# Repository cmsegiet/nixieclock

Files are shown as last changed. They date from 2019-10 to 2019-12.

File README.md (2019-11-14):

# Nixie Tube Clock
Classic Nixie Tube Clock with Bluetooth/WiFi capability

### Background

The nixie tube displays are fascinating to look at and were used in many Cold War era test equipment and various other devices. I was inspired by many nixie tube clock designs to design my own as well. On the surface, this project seemed very easy. However, the deeper I got into the design phase, I quickly realized I had to learn more about designing switching power supplies to get a high voltage rail for the nixie tubes from a much smaller wall adapter. As well as wanting to learn more about transmission lines and impedance matching for implementing a Printed Inverted F Antenna (PIFA) or in general terms, a microstrip antenna with a resonant frequency of 2.4GHz for WiFi capability. 

### Design Requirements

- WiFi-enabled for configuration and additional features such as a remotely accessible timer or scoreboard. 
- RTC module or integrated RTC to allow time-keeping during failures
- A low voltage power supply such as 5V to 12V wall adapter
- Rotary encoder w/ momentary push button for user control
- Direct drive for Nixie Tubes
- 160V to 180V power supply @ 10mA to drive 4 IN-12A Nixie Tubes (Each tube sinks about 2.5mA at 180VDC)

### Design Implementation Features

- Chose nRF52832 MCU from Nordic Semiconductor w/ integrated RTC and Quadrature Decoder for encoder
- Serial to Parallel Shift Register w/ open-drain latched outputs (also 50V Zener clamped common, discussed later) for tubes
- LM3478 Boost/flyback controller for generating 180VDC
- 3.3V boost regulator for MCU
- 5V boost regulator for shift registers and other IC's
- Barrel jack input for wall adapter allowing about 5V to 12V input (protected by TVS diode and Schottky diode, as well as fused)
- I2C Temperature sensor for monitoring overall system temperature
- Later decided to implement this as a multi-board project with a front panel PCB for Nixie's and a control board for MCU for modularity

## Progress

Just a picture of one of the nixie tubes while testing out the power supply section.

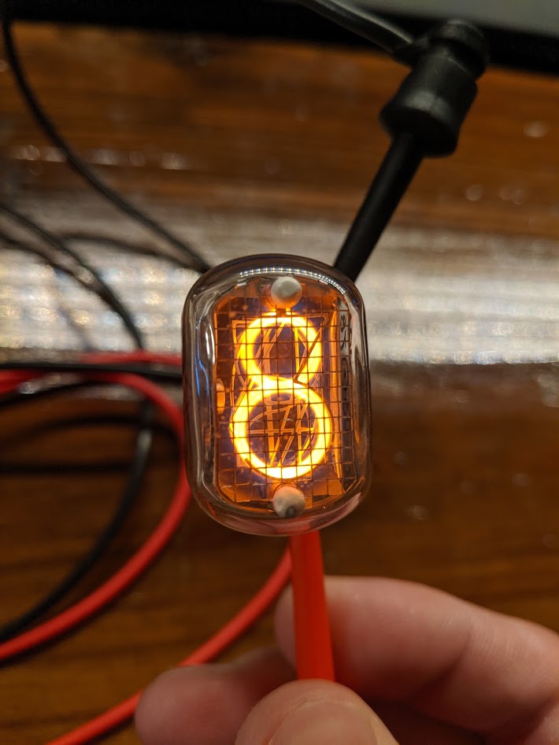
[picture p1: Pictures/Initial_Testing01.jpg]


### 2019-08-18

Purchased a power supply module designed by Paul Andrews on Hackaday to learn more about designing and understanding switching power supply design. Ultimately, I decided to implement most of Paul's design with minor changes such as a different switching FET due to availability of parts. I'll have to monitor the temperature of the new FET although the FET I chose has similar paramters such as Rds(on), Coss, Vds max, gate drive voltage, etc. 

Also spent alot of time in this month learning more about Nixie Tubes and how they work and how they are driven. I learned that they could be driven by a "lower" voltage shift register if the digits that aren't being used at the time are clamped to a common 50V zener on the driver. With this configuration, a dedicated HV driver chip or discrete HV transistors aren't needed. Since the maintainence voltage to keep a Nixie lit after ignition is around 120V, we'll have to lower the supply voltage to around 160V. This will prevent other numbers that aren't being selected from lighting up partially since when they are clamped by a 50V zener, they'll be sitting at around 110V, which is not enough to maintain ignition in a Nixie. By the way 160V is enough to ignite the Nixie's as well, although a common figure tossed around is 170V to 180V.

### 2019-10-12

Finshed most of the schematics, just refining and adding additional features

### 2019-11-05

Finished PCB layout of the control board and figured out how to create a Multi-Board project within Altium Designer. 

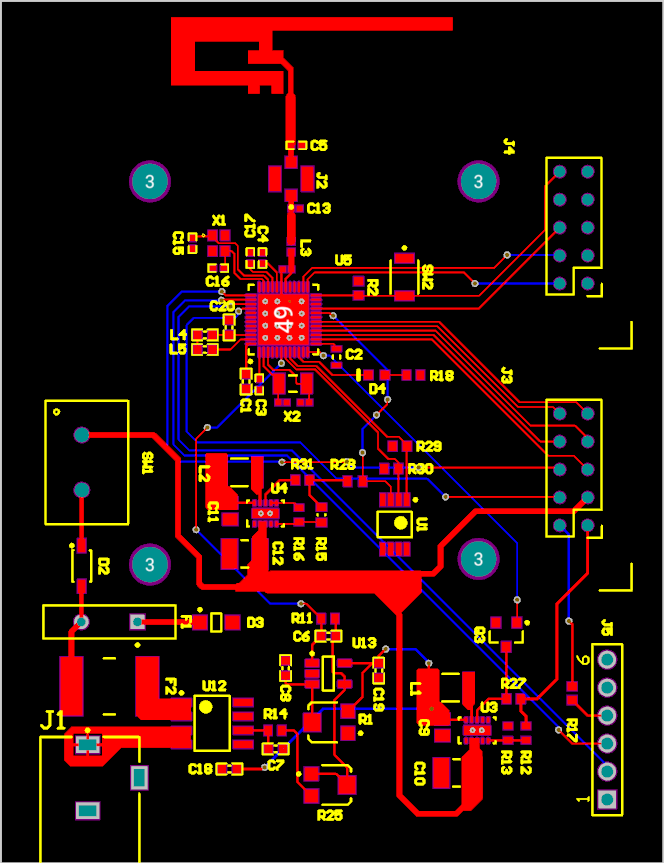
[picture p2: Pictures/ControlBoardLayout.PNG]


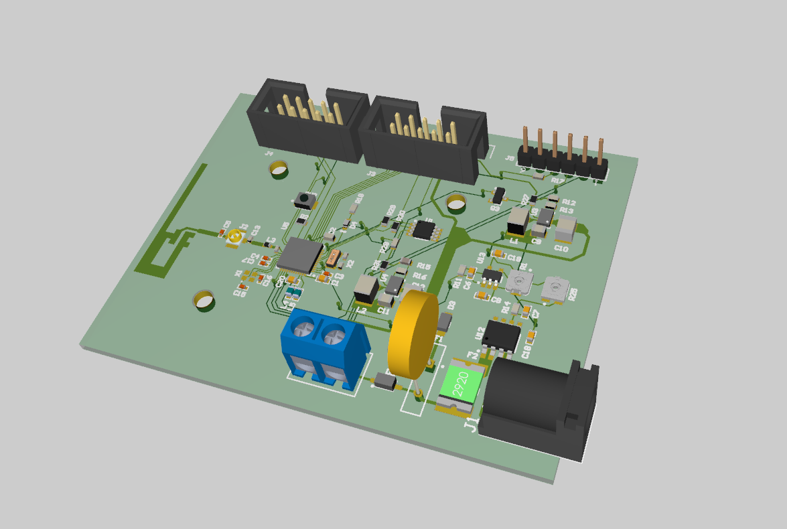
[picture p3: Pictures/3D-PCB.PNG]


### Up Next!

No ground or power planes added yet, but looking good so far! Next up is adding planes and connecting 3v3 through via's to the power plane, as well as adding a via fence for the microstrip antenna ground connections.

I was also thinking about how I could test the antenna S-parameters upon assembly, but this may not be possible due to lack of access to a network analyzer. Unfortunately, the cheap mini VNA's on Amazon and such do not go up to 2.4GHz. Regardless of this shortcoming, I did include a pi-network filter just in case this testing becomes possible.

After finishing the control board, I'll start working on the Nixie Tube board or front panel of the clock. The tricky part with this portion will be finding an adequate source for IN-12A Nixie tube sockets, since the pin dimensions are not consistent enough for a direct IN-12A footprint.

### 2019-11-10

Completed layout of the control board with via shielding along microstrip transmission line, and via stitching GND planes together:

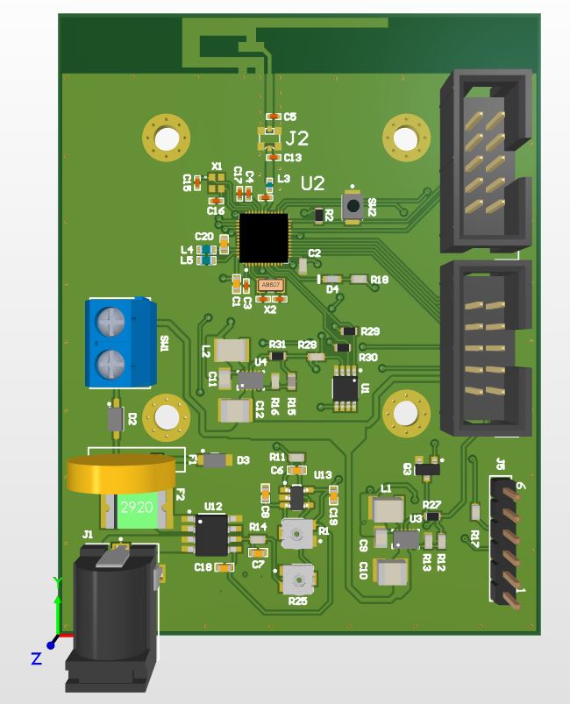
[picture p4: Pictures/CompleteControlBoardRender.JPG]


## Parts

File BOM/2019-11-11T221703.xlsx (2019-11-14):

Index | Quantity | Part Number | Manufacturer Part Number | Description | Customer Reference | Available | Backorder | Unit Price | Extended Price USD
1 | 20 | 587-1441-1-ND | LMK107BJ475KA-T | CAP CER 4.7UF 10V X5R 0603 |  | 20 | 0 | 0.116 | 2.32
2 | 100 | 399-1099-1-ND | C0603C104M4RACTU | CAP CER 0.1UF 16V X7R 0603 |  | 100 | 0 | 0.0161 | 1.61
3 | 100 | 399-1043-1-ND | C0402C104Z4VAC7867 | CAP CER 0.1UF 16V Y5V 0402 |  | 100 | 0 | 0.0081 | 0.81
4 | 100 | 311-1024-1-ND | CC0402JRNPO9BN101 | CAP CER 100PF 50V C0G/NPO 0402 |  | 100 | 0 | 0.0089 | 0.89
5 | 20 | 490-3085-1-ND | GJM1555C1H1R2CB01D | CAP CER 1.2PF 50V C0G/NP0 0402 |  | 20 | 0 | 0.074 | 1.48
6 | 100 | 311-1069-1-ND | CC0603JRNPO9BN101 | CAP CER 100PF 50V C0G/NPO 0603 |  | 100 | 0 | 0.0173 | 1.73
7 | 100 | 311-1080-1-ND | CC0603KRX7R9BB102 | CAP CER 1000PF 50V X7R 0603 |  | 100 | 0 | 0.018 | 1.80
8 | 10 | 490-10511-1-ND | GRM21BR61A226ME51L | CAP CER 22UF 10V X5R 0805 |  | 10 | 0 | 0.222 | 2.22
9 | 10 | 399-8231-1-ND | C1210C225K5RACTU | CAP CER 2.2UF 50V X7R 1210 |  | 10 | 0 | 0.448 | 4.48
10 | 10 | 490-3113-1-ND | GJM1555C1H100JB01D | CAP CER 10PF 50V C0G/NP0 0402 |  | 10 | 0 | 0.179 | 1.79
11 | 100 | 311-1014-1-ND | CC0402JRNPO9BN100 | CAP CER 10PF 50V C0G/NPO 0402 |  | 100 | 0 | 0.0123 | 1.23
12 | 10 | 490-6080-1-ND | GJM1555C1HR80BB01D | CAP CER 0.8PF 50V C0G/NP0 0402 |  | 10 | 0 | 0.13 | 1.30
13 | 100 | 1276-1182-1-ND | CL10A105KP8NNNC | CAP CER 1UF 10V X5R 0603 |  | 100 | 0 | 0.0161 | 1.61
14 | 5 | 1N5819HW-FDICT-ND | 1N5819HW-7-F | DIODE SCHOTTKY 40V 1A SOD123 |  | 5 | 0 | 0.45 | 2.25
15 | 5 | 1727-5320-1-ND | PTVS14VS1UR,115 | TVS DIODE 14V 23.2V CFP3 |  | 5 | 0 | 0.38 | 1.90
16 | 10 | 160-1446-1-ND | LTST-C191KGKT | LED GREEN CLEAR SMD |  | 10 | 0 | 0.201 | 2.01
17 | 5 | F8134CT-ND | 2920L110/60MR | PTC RESET FUSE 60V 1.1A 2920 |  | 5 | 0 | 0.784 | 3.92
18 | 5 | CP-102A-ND | PJ-102A | CONN PWR JACK 2X5.5MM SOLDER |  | 5 | 0 | 0.64 | 3.20
19 | 5 | 490-8450-1-ND | MM8130-2600RB8 | CONN SWF RCPT STR 50 OHM SMD |  | 5 | 0 | 0.37 | 1.85
20 | 10 | ED1543-ND | 302-S101 | CONN HEADER VERT 10POS 2.54MM |  | 10 | 0 | 0.263 | 2.63
21 | 5 | 732-5319-ND | 61300611121 | CONN HEADER VERT 6POS 2.54MM |  | 5 | 0 | 0.33 | 1.65
22 | 10 | 587-1625-1-ND | CBC3225T100MR | FIXED IND 10UH 900MA 172.9 MOHM |  | 10 | 0 | 0.222 | 2.22
23 | 10 | 712-1459-1-ND | L-07C3N9SV6T | FIXED IND 3.9NH 300MA 220 MOHM |  | 10 | 0 | 0.047 | 0.47
24 | 10 | 712-1436-1-ND | L-14C15NJV4T | FIXED IND 15NH 300MA 450 MOHM |  | 10 | 0 | 0.066 | 0.66
25 | 10 | 490-4025-1-ND | LQM18FN100M00D | FIXED IND 10UH 50MA 900 MOHM SMD |  | 10 | 0 | 0.134 | 1.34
26 | 20 | 2N7002K-7DICT-ND | 2N7002K-7 | MOSFET N-CH 60V 0.38A SOT23-3 |  | 20 | 0 | 0.173 | 3.46
27 | 10 | TC33X-103ECT-ND | TC33X-2-103E | TRIMMER 10K OHM 0.1W J LEAD TOP |  | 10 | 0 | 0.277 | 2.77
28 | 100 | P10.0KHCT-ND | ERJ-3EKF1002V | RES SMD 10K OHM 1% 1/10W 0603 |  | 100 | 0 | 0.0264 | 2.64
29 | 100 | P22.0KHCT-ND | ERJ-3EKF2202V | RES SMD 22K OHM 1% 1/10W 0603 |  | 100 | 0 | 0.0264 | 2.64
30 | 100 | 311-787KHRCT-ND | RC0603FR-07787KL | RES SMD 787K OHM 1% 1/10W 0603 |  | 100 | 0 | 0.0094 | 0.94
31 | 100 | 311-150KHRCT-ND | RC0603FR-07150KL | RES SMD 150K OHM 1% 1/10W 0603 |  | 100 | 0 | 0.0094 | 0.94
32 | 100 | P1.0KGCT-ND | ERJ-3GEYJ102V | RES SMD 1K OHM 5% 1/10W 0603 |  | 100 | 0 | 0.0176 | 1.76
33 | 100 | 311-464KHRCT-ND | RC0603FR-07464KL | RES SMD 464K OHM 1% 1/10W 0603 |  | 100 | 0 | 0.0094 | 0.94
34 | 100 | 311-147KHRCT-ND | RC0603FR-07147KL | RES SMD 147K OHM 1% 1/10W 0603 |  | 100 | 0 | 0.0094 | 0.94
35 | 25 | 541-0.0GCT-ND | CRCW06030000Z0EA | RES SMD 0 OHM JUMPER 1/10W 0603 |  | 25 | 0 | 0.0244 | 0.61
36 | 100 | 311-220HRCT-ND | RC0603FR-07220RL | RES SMD 220 OHM 1% 1/10W 0603 |  | 100 | 0 | 0.0094 | 0.94
37 | 100 | 311-100KHRCT-ND | RC0603FR-07100KL | RES SMD 100K OHM 1% 1/10W 0603 |  | 100 | 0 | 0.0094 | 0.94
38 | 3 | 360-3071-ND | M2011SA1W01 | SWITCH TOGGLE SPST 6A 125V |  | 3 | 0 | 4.66 | 13.98
39 | 5 | SW1020CT-ND | B3U-1000P | SWITCH TACTILE SPST-NO 0.05A 12V |  | 5 | 0 | 0.84 | 4.20
40 | 10 | 568-4768-1-ND | LM75BDP,118 | SENSOR DIGITAL -55C-125C 8TSSOP |  | 10 | 0 | 0.631 | 6.31
41 | 5 | 1490-1052-1-ND | NRF52832-QFAA-R | IC RF TXRX+MCU BLUETOOTH 48VFQFN |  | 5 | 0 | 5.73 | 28.65
42 | 10 | 296-39451-1-ND | TPS62175DQCR | IC REG BUCK BST ADJ 500MA 10WSON |  | 10 | 0 | 1.471 | 14.71
43 | 3 | 620-1645-1-ND | ACS723LLCTR-20AU-T | SENSOR CURRENT HALL 20A DC |  | 3 | 0 | 5.27 | 15.81
44 | 5 | 296-41475-1-ND | OPA344NA/3K | IC OPAMP GP 1 CIRCUIT SOT23-5 |  | 5 | 0 | 1.51 | 7.55
45 | 10 | SER4079CT-ND | FA-128 32.0000MF20X-K5 | CRYSTAL 32MHZ 10PF SMD |  | 10 | 0 | 0.495 | 4.95
46 | 5 | 535-11937-1-ND | ABS07-120-32.768KHZ-T | CRYSTAL 32.7680KHZ 6PF SMD |  | 5 | 0 | 0.77 | 3.85

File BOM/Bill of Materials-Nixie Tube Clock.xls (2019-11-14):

Comment | Description | Designator | Footprint | LibRef | Quantity
Inverted F Antenna |  | ANT1 | PIFA | Inverted F Antenna | 1
4.7µF | Capacitor, X5R, ±10% | C1 | CAPC1608X06L |  | 1
100nF | Capacitor, X5R, ±10% | C2 | CAPC1608X06L |  | 1
0.1uF | Capacitor, NP0, ±0.1pF | C3 | CAPC1005X04L |  | 1
100pF | Capacitor, NP0, ±0.1pF | C4, C17 | CAPC1005X04L |  | 2
1.2pF | Capacitor, NP0, ±0.1pF | C5 | CAPC1005X04L |  | 1
100pF | Capacitor, X5R, ±10% | C6 | CAPC1608X06L |  | 1
1nF | Capacitor, X5R, ±10% | C7 | CAPC1608X06L |  | 1
0.1uF | Capacitor, X5R, ±10% | C8, C18, C19 | CAPC1608X06L |  | 3
GRM21BR61A226ME51L | Chip Capacitor, 22 uF, +/- 20%, 10 V, -55 to 85 degC, 0805 (2012 Metric), RoHS, Tape and Reel | C9, C11 | CAPC2013X140X45LL15T25 | CMP-2000-06340-1 | 2
CAP 2.2uF 50V 1210(3225) | CAP 2.2uF 50V ±10% 1210 (3225 Metric) Thickness 2.2mm SMD | C10, C12 | CAPC1210(3225)220_N | CMP-1038-02098-1 | 2
10pF | Capacitor, NP0, ±0.1pF | C13, C15, C16, C21, C22 | CAPC1005X04L |  | 5
0.8pF | Capacitor, NP0, ±0.1pF | C14 | CAPC1005X04L |  | 1
1uF | Capacitor, X5R, ±10% | C20 | CAPC1608X06L |  | 1
1N5819HW-7-F | 1.0 A Surface Mount Schottky Barrier Rectifier, 40 V, -65 to 125 degC, 2-Pin SOD-123 Package, RoHS, Tape and Reel | D2 | DIOD-SOD-123-2_V | CMP-0303-00003-1 | 1
TVS 23.2V @ 17.2A (10/1000) | TVS DIODE 14V 23.2V CFP3 | D3 | ONSC-SOD-123FL-2-498_V | PTVS14VS1UR,115 | 1
LTST-C191KGKT | Chip LED, Green, 574 nm, 40 pF, -55 to 85 degC, 2-Pin SMD, RoHS, Tape and Reel | D4 | LITE-ON-LTST-C191KRKT-2_V | CMP-2000-05198-1 | 1
60V 1.1A | PTC RESET FUSE 60V 1.1A 2920 | F1, F2 | PTC 2920 | 2920L110/60MR | 2
PJ-102A | DC Power Jack, 2.5 A, -25 to 85 degC, 3-Pin THD, RoHS | J1 | CUI-PJ-102A_V | CMP-2000-06899-1 | 1
MM8130-2600RB8 | Conn Coaxial RCP 0Hz to 6GHz 50Ohm Solder ST SMD Reel | J2 | COAXIAL-SWF | MM8130-2600RB8 | 1
302-S101 | CONN HEADER VERT 10POS 2.54MM | J3 | 10pin Header TH | 302-S101 | 1
10pin dual row 2.54" Shrouded |  | J4 | 10pin Header TH | JTAG Header | 1
61300611121 | THT Vertical Pin Header WR-PHD, Pitch 2.54 mm, Single Row, 6 pins | J5 | 61300611121 | CMP-1502-01070-1 | 1
CBC3225T100MR | TAIYO YUDEN - CBC3225T100MR - INDUCTOR, 10UH, 20%, 1210 CASE | L1, L2 | MURA-1210_H_2.7_N | CBC3225T100MR | 2
3.9nH | Inductor, 320mA, ±5% | L3 | INDC1005X04L |  | 1
15nH | Inductor, 80mA, ±10% | L4 | INDC1608X06L |  | 1
10µH | Inductor, 80mA, ±10% | L5 | INDC1608X06L |  | 1
MH |  | MH1, MH2, MH3, MH4 | Mounting | MH | 4
2N7002K-7 | DIODES INC. - 2N7002K-7 - MOSFET, N CH, 60V, 0.3A, SOT-23 | Q3 | SOT95P245X110-3N | 2N7002K-7 | 1
TC33X-2-103E | Trimming Potentiometer, 10000 Ohm, -40 to 100 degC, 3-Pin SMD, RoHS, Tape and Reel | R1, R25 | BOUR-TC33X-2_V | CMP-2100-03695-1 | 2
ERJ3EKF1002V | Chip Resistor, 10 KOhm, +/- 1%, 0.1 W, -55 to 155 degC, 0603 (1608 Metric), RoHS, Tape and Reel | R2, R27, R29, R30, R31 | RESC1609X55X30LL15T15 | CMP-2000-07452-1 | 5
ERJ3EKF2202V | 22k 0603 | R11 | RESC1608X55X30LL15T15 | CMP-2000-00337-1 | 1
RC0603FR-07787KL | 787k 0603 | R12 | RESC1608X55X25LL10T15 | CMP-2000-04136-1 | 1
RC0603FR-07150KL | Chip Resistor, 150 KOhm, +/- 1%, 0.1 W, -55 to 155 degC, 0603 (1608 Metric), RoHS, Tape and Reel | R13 | RESC1608X55X25LL10T15 | CMP-1659-00044-1 | 1
ERJ-3GEYJ102V | 10k 0603 | R14 | RESC1608X55X30LL15T15 | CMP-2000-00703-1 | 1
464K | 464K 0.1W 1% 0603 (1608 Metric) SMD | R15 | RESC0603(1608)_L | CMP-1012-00811-1 | 1
RC0603FR-07147KL | Chip Resistor, 147 KOhm, +/- 1%, 0.1 W, -55 to 155 degC, 0603 (1608 Metric), RoHS, Tape and Reel | R16 | RESC1608X55X25LL10T15 | CMP-2000-06928-1 | 1
CRCW06030000Z0EA | 0, 0603, 1/10W | R17 | RESC1609X55X30LL10T20 | CMP-2000-03816-1 | 1
ERJ-3GEYJ221V |  | R18 | RESC1608X55X30LL15T15 | CMP-2000-00746-1 | 1
RC0603FR-07100KL | Chip Resistor, 100 KOhm, +/- 1%, 0.1 W, -55 to 155 degC, 0603 (1608 Metric), RoHS, Tape and Reel | R28 | RESC1608X55X25NL10T15 | CMP-2100-03662-1 | 1
M2011SA1W01 | SWITCH TOGGLE SPST 6A 125V | SW1 | 2pin Screw Terminal | M2011SA1W01 | 1
B3U-1000P | Ultra-Small Tactile Switch, 0.05 A, 12 V, -25 to 70 degC, 2-Pin SMD, RoHS, Tape and Reel | SW2 | OMRON-B3U-1000_V | CMP-2100-03586-1 | 1
LM75BDP | NXP - LM75BDP,118 - DIGITAL TEMPERATURE SENSOR 11 BIT, +/-3C, TSSOP-8 | U1 | TSOP72P490X110-8N | LM75BDP,118 | 1
NRF52832-QFAA-R | Multiprotocol Bluetooth Smart, ANT/ANT+ and Proprietary System-on-Chip, 2.4 GHz, 256 KB FLASH, 1.7 to 3.6 V, -40 to 85 degC, 48-Pin QFN, RoHS, Tape and Reel | U2 | NRSC-QF-48_M | CMP-2100-03661-1 | 1
TPS62175 | Conv DC-DC 4.75V to 28V Synchronous Step Down Single-Out 1V to 6V 0.5A 10-Pin WSON EP T/R | U3, U4 | DQC0010A | TPS62175DQCR | 2
ACS723 | SENSOR CURRENT HALL 20A DC | U12 | SOIC127P600X175-8N | ACS723LLCTR-20AU-T | 1
OPA344 | Low Power, Single-Supply, Rail-to-Rail Operational Amplifier MicroAmplifier(TM) Series, 2.5 to 5.5 V, -55 to 125 degC, 5-pin SOT23 (DBV5), Green (RoHS & no Sb/Br) | U13 | DBV0005A_M | CMP-0272-00881-3 | 1
32MHz | CRYSTAL 32MHZ 10PF SMD | X1 | *OSCCC200X160X50N | FA-12832.0000MF20X-K5 | 1
ABS07-120-32.768KHZ-T | Tuning Fork Crystal, 32.768 KHz, +/- 20 ppm, -40 to 85 degC, 2-Pin SMD, RoHS, Tape and Reel | X2 | ABRA-ABS07_A_V | CMP-2000-07587-1 | 1

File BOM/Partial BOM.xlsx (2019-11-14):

Reference Designator | Description | Manufacturer | Manufacturer PN | Supplier 1 | Supplier 1 PN | Qtn | Footprint OK
J1 | Barrel jack connector | CUI | PJ-102A | Digi-key | CP-102A-ND | 1 | Yes
D3 | TVS Diode 23.2V @ 17.2A (10/1000) | Nexperia USA Inc. | PTVS14VS1UR,115 | Digi-key | 1727-5320-1-ND | 1 | Yes
F2 | PTC Fuse, 60V, 1.1A | Littelfuse Inc. | 2920L110/60MR | Digi-key | F8134CT-ND | 1 | Yes
D2 | DIODE SCHOTTKY 40V 1A SOD123 | Diodes Inc. | 1N5819HW-7-F | Digi-key | 1N5819HW-FDICT-ND | 1 | Yes
U3, U4 | Buck Regulators | TI | TPS62175 | Digi-key | 296-39451-1-ND | 2 | Yes
U13 | IC OPAMP GP 1 CIRCUIT SOT23-5 | TI | OPA344NA/3K | Digi-key | 296-41475-1-ND | 1 | Yes
R25, R1 | TRIMMER 10K OHM 0.1W J LEAD TOP | Bourns | TC33X-2-103E | Digi-key | TC33X-103ECT-ND | 2 | Yes
U12 | SENSOR CURRENT HALL 20A DC | Allegro MicroSystems | ACS723LLCTR-20AU-T | Digi-key | 620-1645-1-ND | 1 | Yes
U1 | SENSOR DIGITAL -55C-125C 8TSSOP | NXP | LM75BDP,118 | Digi-key | 568-4768-1-ND | 1 | Yes
U2 | IC RF TXRX+MCU BLUETOOTH 48VFQFN | Nordic Semi | NRF52832-QFAA-R | Digi-key | 1490-1052-1-ND | 1 | Yes
 |  |  |  | Digi-key
 |  |  |  | Digi-key
 |  |  |  | Digi-key
 |  |  |  | Digi-key
 |  |  |  | Digi-key
 |  |  |  | Digi-key
 |  |  |  | Digi-key
 |  |  |  | Digi-key
 |  |  |  | Digi-key
 |  |  |  | Digi-key
 |  |  |  | Digi-key
 |  |  |  | Digi-key
 |  |  |  | Digi-key
 |  |  |  | Digi-key
 |  |  |  | Digi-key
 |  |  |  | Digi-key
 |  |  |  | Digi-key
 |  |  |  | Digi-key

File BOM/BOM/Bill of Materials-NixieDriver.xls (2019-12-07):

Comment | Description | Designator | Footprint | LibRef | Quantity
CC0603KRX7R7BB104 | Ceramic Multilayer Capacitor, 100 nF, +/- 10%, 50 V, -55 to 155 degC, 0603 (1608 Metric), RoHS, Tape and Reel | C1 | CAPC1608X90X40ML10T20 | CMP-2000-05002-1 | 1
0.22uF 250V | CAP CER 0.22UF 250V X7R 1210 | C2 | MURA-1210_H_2.7_N | C3225X7R2E224K200AA | 1
CC0603KRX7R9BB103 | Chip Capacitor, 10 nF, +/- 10%, 50 V, -55 to 125 degC, 0603 (1608 Metric), RoHS, Tape and Reel | C3, C4 | CAPC1608X90X40ML10T20 | CMP-2100-03600-1 | 2
360pF | Capacitor, X5R, ±10% | C5 | CAPC1608X06L |  | 1 | Change to 0805
22nF | Capacitor, X5R, ±10% | C6 | CAPC1608X06L |  | 1
100uF | Chip Capacitor, 100 uF, +/- 20%, 16 V, -55 to 85 degC, 1210 (3225 Metric), RoHS, Tape and Reel | C7 | CAPC3225X270X60ML30T30 | CMP-2000-05020-1 | 1
0.01uF | Capacitor, X5R, ±10% | C8 | CAPC1608X06L |  | 1
300V 1A | DIODE GEN PURP 300V 1A SMA | D1 | DO-219AB | ES1F | 1
PEC11L-4115F-S0020 | LOW PROFILE ENCODER, 11 MM, CONTACT RATING 10 MA - 5 VDC | ENC1 | PEC11L | PEC11L-4115F-S0020 | 1
302-S101 | CONN HEADER VERT 10POS 2.54MM | J1 | 10pin Header TH | 302-S101 | 1
MH |  | MH1, MH2, MH3, MH4 | Mounting | MH | 4
IN-12A Nixie Tube |  | NT1, NT2, NT3, NT4 | IN-12 Nixie | IN-12A Nixie Tube | 4
FDMS86101 | MOSFET 100/20V Nch Power Trench | Q1 | 8-PQFN | FDMS86101 | 1
2N7002K-7 | DIODES INC. - 2N7002K-7 - MOSFET, N CH, 60V, 0.3A, SOT-23 | Q2 | SOT95P245X110-3N | 2N7002K-7 | 1
ERJ3EKF1002V | Chip Resistor, 10 KOhm, +/- 1%, 0.1 W, -55 to 155 degC, 0603 (1608 Metric), RoHS, Tape and Reel | R1, R2, R3, R23, R24, R26 | RESC1609X55X30LL15T15 | CMP-2000-07452-1 | 6
249R |  | R4 | RESC3225X70X50LL20T20 | CMP-2005-03224-1 | 1
1M |  | R5 | RESC2013X70X40ML20T20 | CMP-2001-04378-1 | 1
47k |  | R6 | RESC2013X50X30ML20T20 | CMP-2001-03939-1 | 1
453k | 453k | R7 | RESC2013X60X35NL10T20 | CMP-2001-01154-1 | 1 |  | ordered 300k
4.7k | Chip Resistor, 4.7 KOhm, +/- 1%, 0.125 W, -55 to 155 degC, 0805 (2012 Metric), RoHS, Tape and Reel | R8 | RESC2013X70X40NL20T20 | CMP-1665-00006-4 | 1
0.06R 1W | RES 0.06 OHM 1% 1W 2010 | R9 | RES2010 | CSRN2010FK60L0 | 1
10.2k | Chip Resistor, 10.2 KOhm, +/- 1%, 0.1 W, -55 to 155 degC, 0603 (1608 Metric), RoHS, Tape and Reel | R10 | RESC1608X55X25LL10T15 | CMP-2000-06926-1 | 1
CRCW080522K0FKEA |  | R19, R20, R21, R22 | RESC2013X50X30ML20T20 | CMP-2001-03688-1 | 4
749196141 | Flexible Transformer for DC/DC Converter WE-FLEX, L=8.5µH | T1 | ER11_5 | CMP-1376-00017-1 | 1
SN74LVC3G14DCTR | Triple Schmitt-Trigger Inverter, DCT0008A, LARGE T&R | U1 | DCT0008A_N | CMP-0859-00539-4 | 1
LM3478MAX/NOPB | High Efficiency Low-Side N-Channel Controller for Switching Regulator, 8-pin Narrow SOIC, 2500 Reel | U2 | D0008A_N | CMP-0063-01438-3 | 1
TPIC6B595 | IC PWR 8-BIT SHIFT REGIS 20-SOIC | U6, U7, U8, U9, U10 | SOIC127P1030X265-20N | TPIC6B595DWRG4 | 5
SN74HC04DR | Hex Inverters, D0014A, LARGE T&R | U11 | D0014A_M | CMP-1615-00282-2 | 1

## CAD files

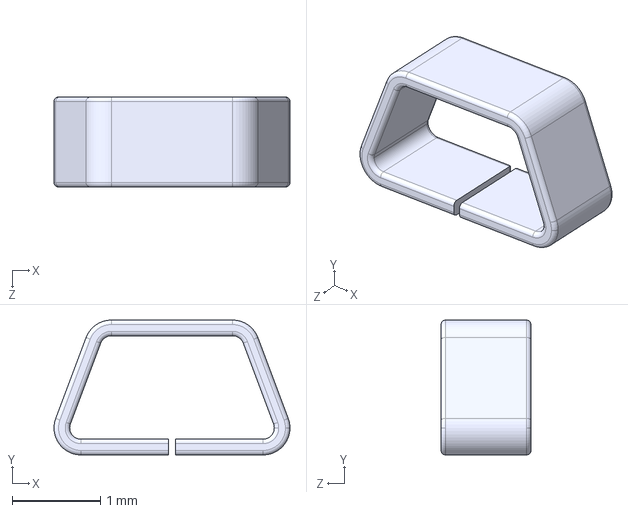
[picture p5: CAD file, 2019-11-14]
Hardware/3D Models/User Library-keystone_5015.step
2.67 x 1.52 x 1.02 mm

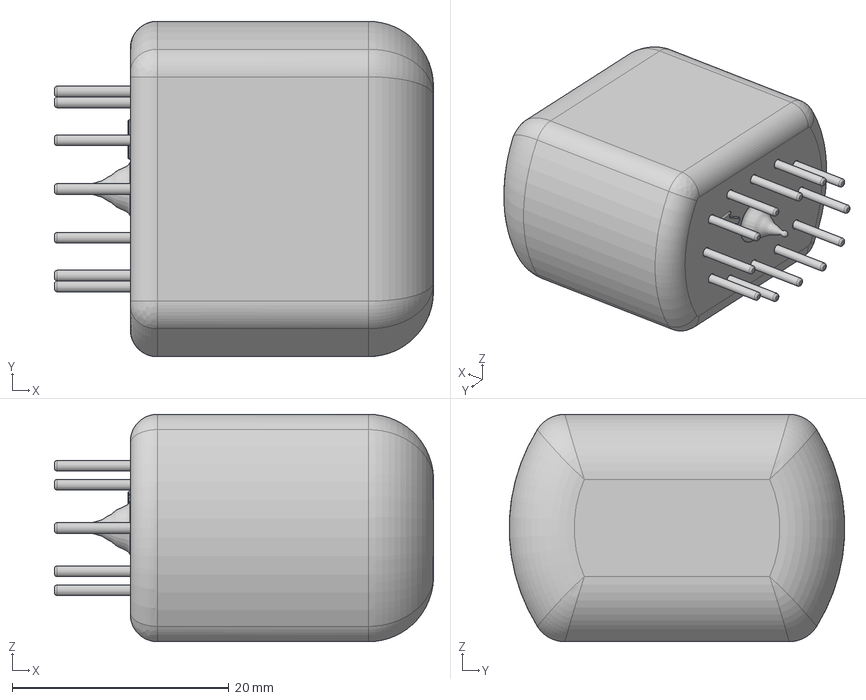
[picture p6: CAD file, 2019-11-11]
Hardware/3D Models/IN-12A.stp
35.0 x 31.0 x 21.0 mm

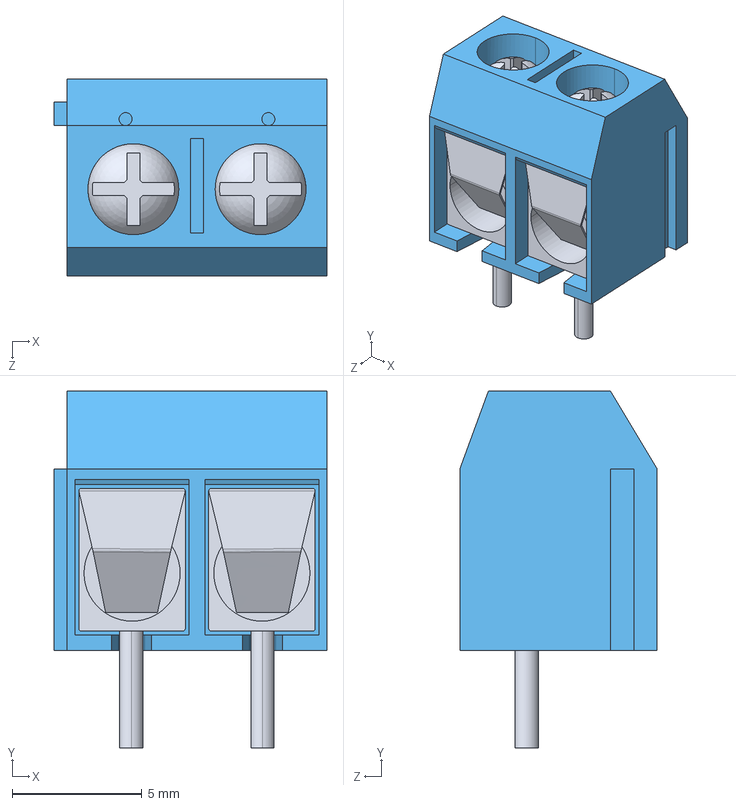
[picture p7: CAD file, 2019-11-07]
Hardware/3D Models/User Library-bornera-1.step
10.5 x 13.8 x 7.60 mm

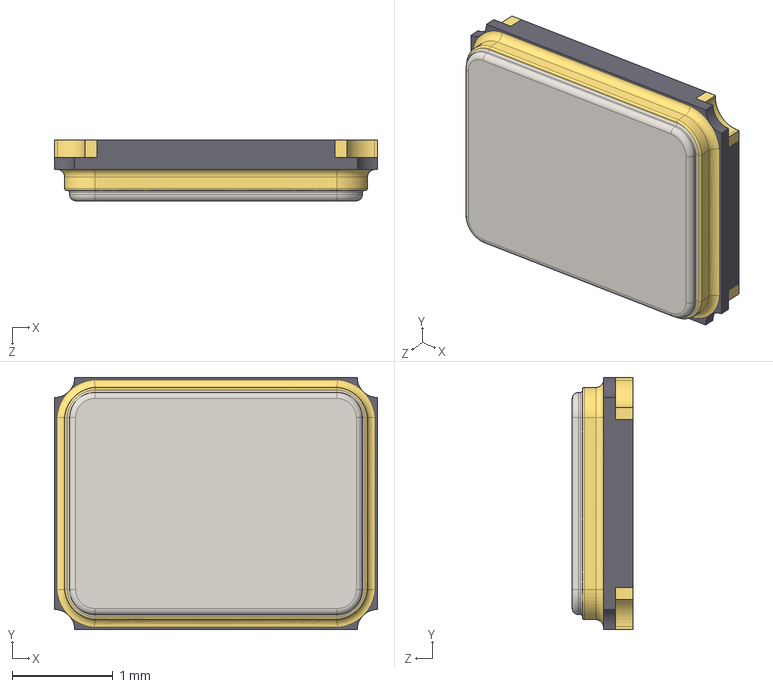
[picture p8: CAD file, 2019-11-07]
Hardware/3D Models/User Library-tsx-3225-1.step
3.20 x 2.50 x 0.6 mm

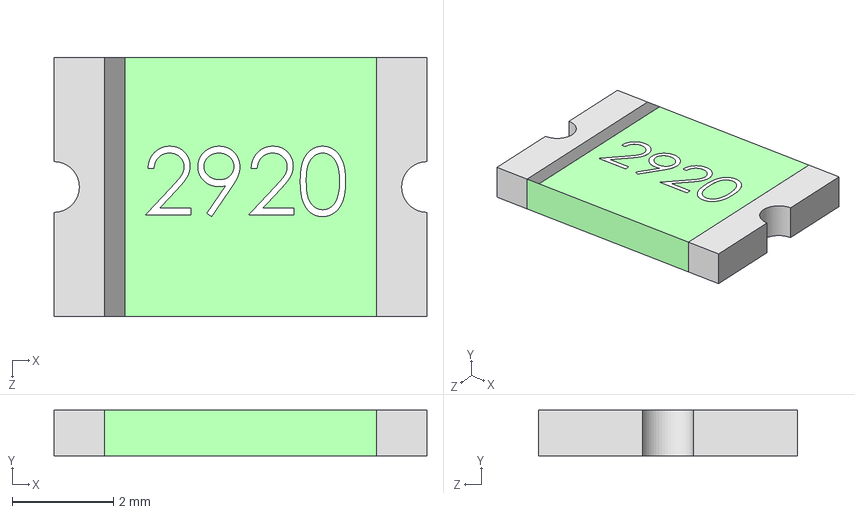
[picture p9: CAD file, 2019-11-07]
Hardware/3D Models/User Library-Fuse 2920.step
7.36 x 0.901 x 5.12 mm

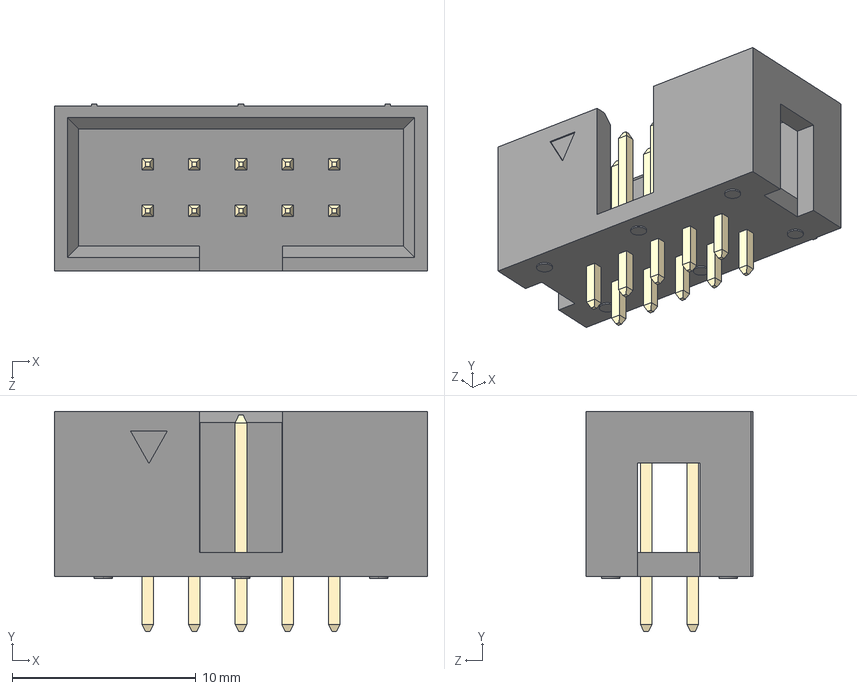
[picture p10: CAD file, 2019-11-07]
Hardware/3D Models/User Library-BH_10_V.step
20.3 x 12.0 x 9.10 mm

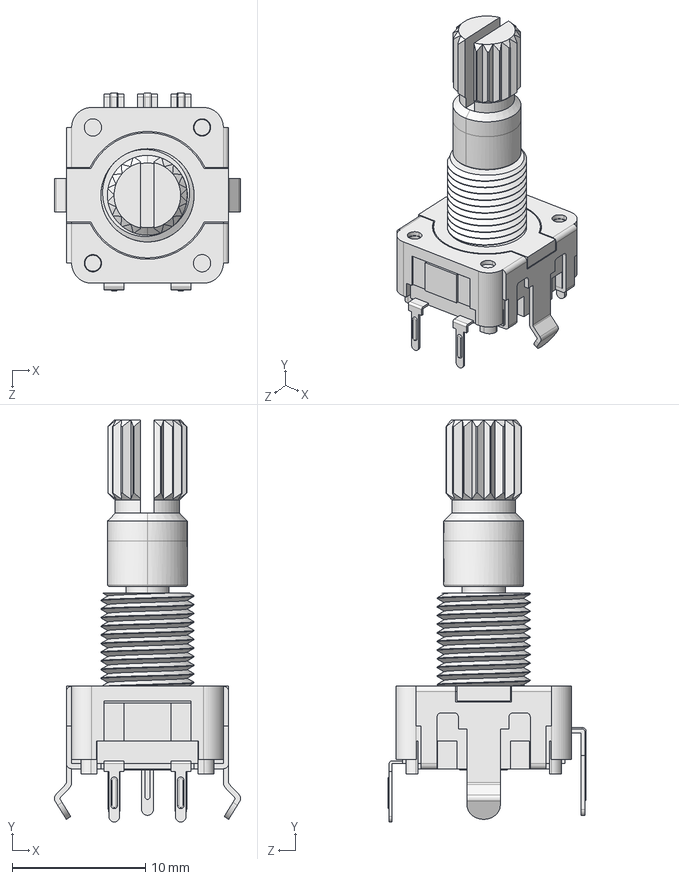
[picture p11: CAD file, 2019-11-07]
Hardware/3D Models/User Library-pec11r-4x20k-sxxxx.step
14.0 x 30.2 x 14.9 mm

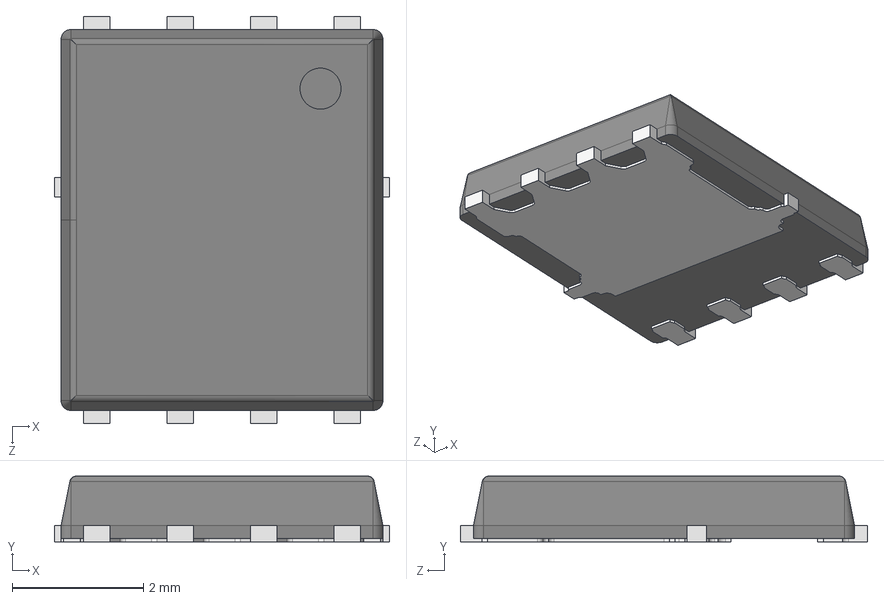
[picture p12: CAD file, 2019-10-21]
Hardware/3D Models/User Library-PQFN8_5X6.step
5.10 x 1.00 x 6.20 mm

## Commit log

2019-10-09 Initial commit.
    [Book1.xlsx, HVDC Power.SchDoc, Input - 3v3 Power Supply.SchDoc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]
2019-10-09 Removed unnecessary files
    [NixieTubeClock.kicad_pcb, NixieTubeClock.sch]
2019-10-09 Folder and name restructure
    [Book1.xlsx, Rough Flyback Converter Calculations.xlsx]
2019-10-21 Added Nixie driver, and changed low voltage rails
    [HVDC Power.SchDoc, Input - 3v3 Power Supply.SchDoc, Low Voltage Power Supplies.SchDoc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]
2019-11-01 Schematic mostly done.
    [HVDC Power.SchDoc, Low Voltage Power Supplies.SchDoc, MCU.SchDoc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]
2019-11-07 Layout mostly done on Control Board, need planes
    [Copy of HVDC Power.SchDoc, HVDC Power.SchDoc, Low Voltage Power Supplies.SchDoc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]
2019-11-07 Add pictures of control board
2019-11-10 All layout complete, need via stitching
    [Low Voltage Power Supplies.SchDoc, MCU.SchDoc, MainBoard.PcbDoc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]
2019-11-10 Generated Gerbers, need test points added.
    [HVDC Power.SchDoc, MCU.SchDoc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]
2019-11-11 Nixie footprint & driver layout begins
    [HVDC Power.SchDoc, IN-12A.stp, Nixie Tube Drivers.SchDoc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]
2019-11-14 Control board done, working on front panel board
    [2019-11-11T221703.xlsx, Bill of Materials-Nixie Tube Clock.xls, HVDC Power.SchDoc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]
2019-12-07 Second revision of Nixie Driver board
    [Bill of Materials-NixieDriver.xls, HVDC Power.SchDoc, MCU.SchDoc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]
